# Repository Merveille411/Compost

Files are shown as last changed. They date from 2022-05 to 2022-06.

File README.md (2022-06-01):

# Compost Connecté

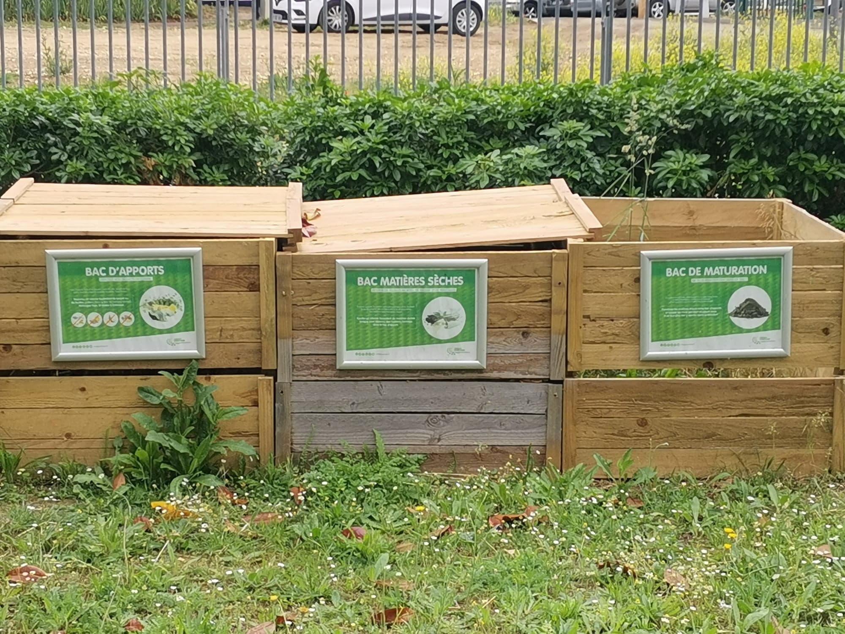
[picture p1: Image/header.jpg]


## Sommaire
- [Introduction](#introduction)
- [Résulat et problèmes rencontrés](#résulat-et-problèmes-rencontrés)
- [Conclusion](#conclusion)
- [À propos des dossiers](#à-propos-des-dossiers)

## Introduction

L’objectif de notre projet était de rendre le compost de l'ENSEA connecté et autonome, qu'il puisse envoyer un message d'alerte si les différents paramètre ne sont pas conforme.   
Nous arrivons donc au cahier des charges suivant :    
        
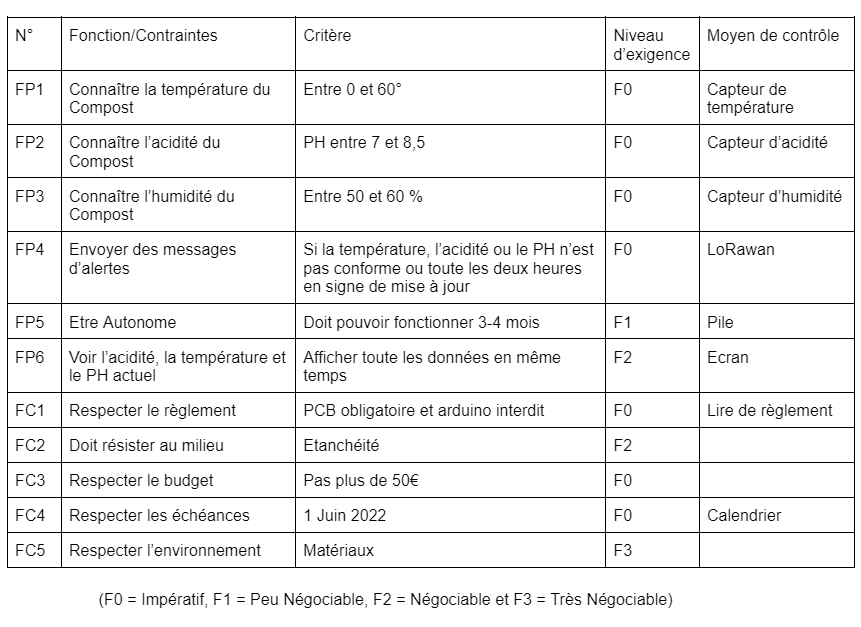
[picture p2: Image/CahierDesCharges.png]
     

FP1 : La référence du capteur de température est [SA56004AD](https://www.nxp.com/part/SA56004AD#/), il est à l’ENSEA. Il lui faut une tension entre 3,3 et 5 V et un courant de 100 microA. [Datasheet](https://www.nxp.com/docs/en/brochure/75015962.pdf)    
FP2 : La référence du capteur d’acidité est [32638](https://www.gotronic.fr/art-sonde-ph-interface-sen0161-21552.htm), il n’est pas à l’ENSEA, il coûte 32,30€. Il lui faut une tension de 5V. [Datasheet](https://wiki.dfrobot.com/PH_meter_SKU__SEN0161_)    
FP3 : La référence du capteur d’humidité est [893-7082](https://fr.rs-online.com/web/p/capteurs-de-temperature-et-d-humidite/8937082), il n’est pas à l’ENSEA, il coûte 11,26€. Il lui faut une tension de 5V et un courant de 1,5 mA. [Datasheet](https://www.te.com/commerce/DocumentDelivery/DDEController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)  
FP6 : La référence de l’écran est [4440](https://www.adafruit.com/product/4440), il est à l’ENSEA. Il lui faut une tension entre 3,3 et 5 V et un courant de 90 mA. [Datasheet](https://cdn-learn.adafruit.com/downloads/pdf/monochrome-oled-breakouts.pdf)   
    
Puisque nous avons deux capteurs et l'écran en connection I2C et le LoRa en connection UART, nous utiliserons un microprocesseur [STM32L412KBT6](https://www.digikey.fr/fr/products/detail/stmicroelectronics/STM32L412KBT6/9656219). Il est a l'ENSEA; [Datasheet](https://www.st.com/resource/en/datasheet/stm32l412kb.pdf)   
    
Le projet avancera d'après le planning prévisionnel suivant :
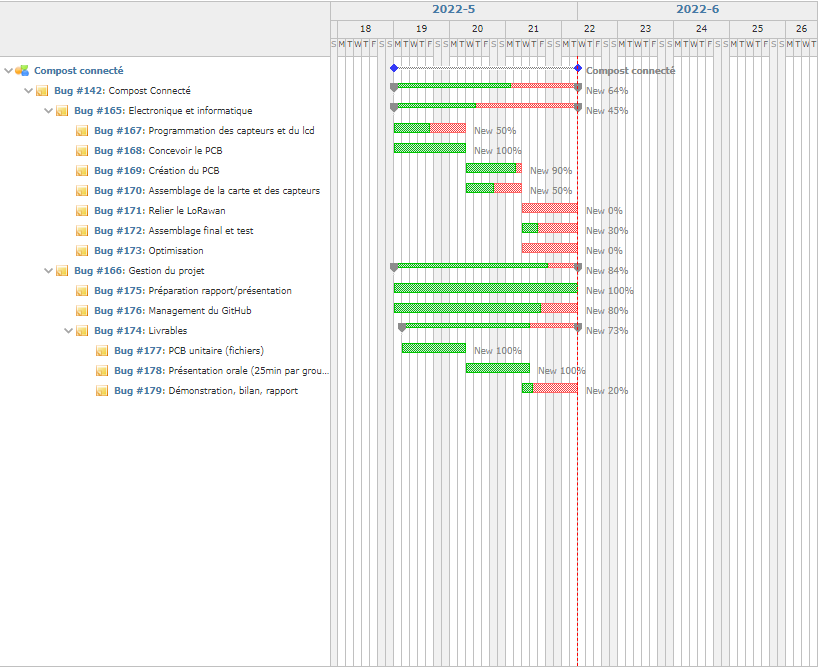
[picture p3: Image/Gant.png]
   

Les interactions entre les différents composants ainsi que la structure de base du projet est illustré de la manière suivante :
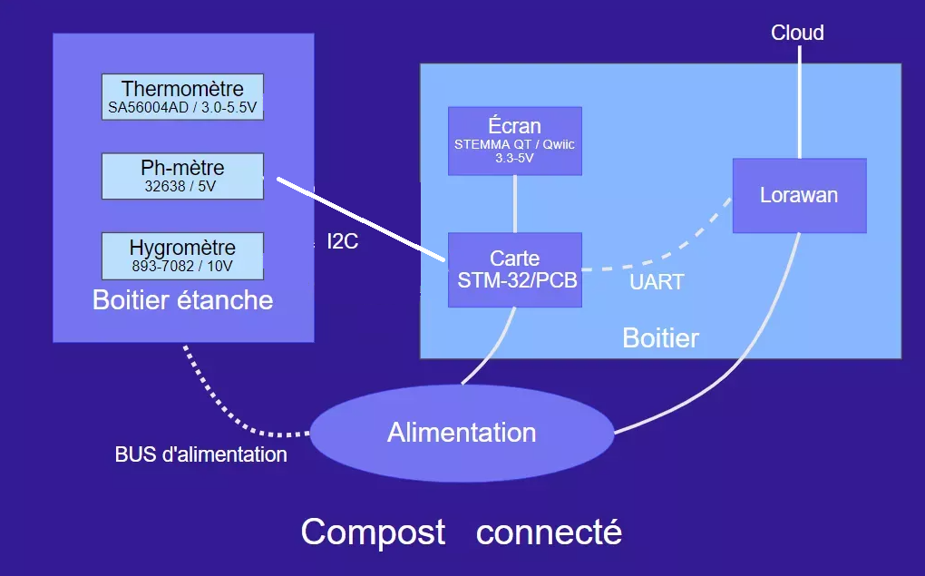
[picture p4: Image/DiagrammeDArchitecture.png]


## Résulat et problèmes rencontrés

Globalement, pour tout les PCB, le fichier contraintes a été respecté sauf pour celui du capteur de température. Donc notre PCB est inutilisable.               
Sur le PCB du compost, on a fait des erreurs sur les pin utilisés par le microprocesseur. Ducoup, on ne peut pas connecté le module LoRa et les capteur en I2C en même temps.
                
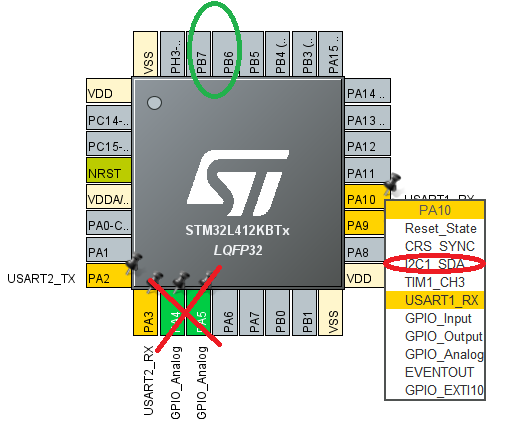
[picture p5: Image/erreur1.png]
   
                
Comme on peut le voir, le pA10 et pA9 permettent soit de faire la connection en UART ou en I2C tandis que pA4 et pA5 ne permet ne permet pas la connection en I2C comme prévu et il aurait fallu donc utilisé les pin pB6 et pB7.
                
Malgré ça, le PCB du compost et du capteur d'humidité ont leurs composants soudé parfaitement, sans erreur et les valeurs entre chaque point sont juste.               
                
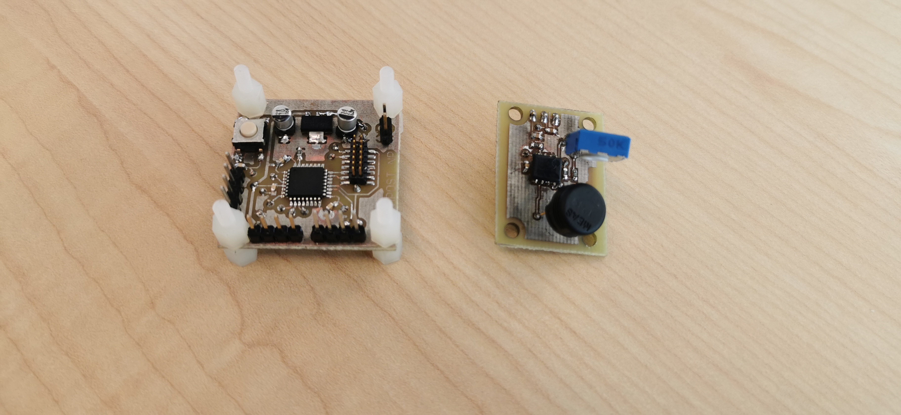
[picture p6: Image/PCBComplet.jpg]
   

De plus, le PCB du compost, qui contient le microprosseur a pu être flashé et donc il est prêt à être coder et à l'utilisation.         
        
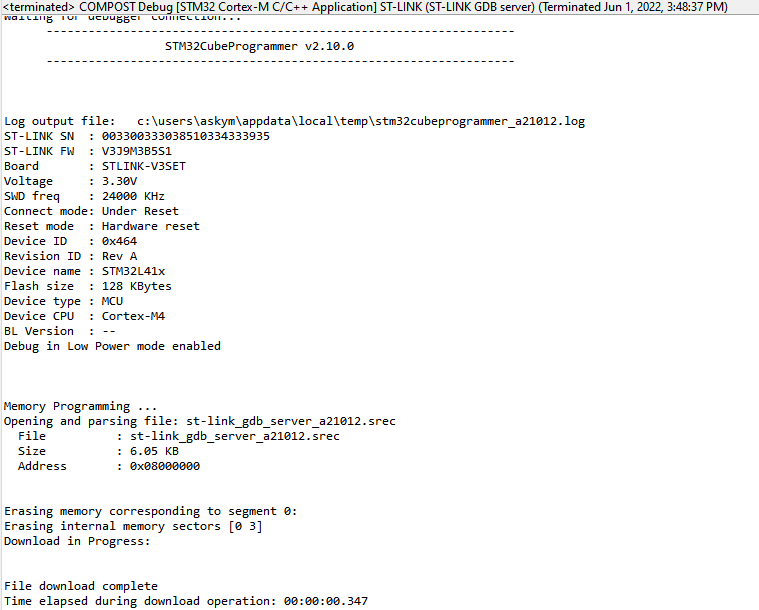
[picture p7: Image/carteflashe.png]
        
                
## Conclusion   
        
Pour conclure, il nous restez plus qu'à faire le code des différents composants et de réunir l’ensemble des parties pour faire un test global. Il faudrait aussi corriger les choix des pin sur le schéma du PCB du compost afin d'avoir la connection en I2C et UART. Ce projet nous a permis d'avoir une meilleur prise en main sur des logiciels du type EAGLE ou STM32CubeIDE. Nous avons également appris à s'attribuer des tâches de manière efficace, à communiquer et de se fixer des objectifs tout le long du projet.

## À propos des dossiers
**EAGLE/**    
                
  &emsp; &emsp;  **DRU/**    
  &emsp; &emsp;  Ce dossier contient le fichier contraintes utiliser pour les différents PCB du projet    
  &emsp; &emsp; `ENSEA_2022_04_08.dru`: Le fichier contrainte de l'ensea                
                
  &emsp; &emsp;  **Libraries/**    
  &emsp; &emsp;  Ce dossier contient tout les libraries des composants utiliser dans ce projet    
  &emsp; &emsp; `c1.lbr`: La librarie d'un condensateur de 470 uF utilisé dans le PCB de l'alimentation     
  &emsp; &emsp; `c2.lbr`: La librarie d'un condensateur de 100 uF utilisé dans le PCB de l'alimentation     
  &emsp; &emsp; `c3.lbr`: La librarie d'un condensateur de 470 pF utilisé dans le PCB de l'alimentation      
  &emsp; &emsp; `CapteurHumidite.lbr`: La librarie du capteur d'humidité     
  &emsp; &emsp; `CapteurTemperature.lbr`: La librarie du capteur de température     
  &emsp; &emsp; `cin.lbr`: La librarie d'un condensateur de 10 uF utilisé dans le PCB de l'alimentation ainsi que dans le PCB complet du compost      
  &emsp; &emsp; `cout.lbr`: La librarie d'un condensateur de 22 uF utilisé dans le PCB de l'alimentation ainsi que dans le PCB complet du compost      
  &emsp; &emsp; `l.lbr`: La librarie d'une bobine de 220 uH utilisé dans le PCB de l'alimentation     
  &emsp; &emsp; `MC34063A.lbr`: La librarie du régulateur à découpage utilisé dans le PCB de l'alimentation    
  &emsp; &emsp; `RegLineaire.lbr`: La librarie du régulateur linéaire utilisé dans le PCB de l'alimentation ainsi que dans le PCB complet du compost     
  &emsp; &emsp; `STM32_librairy.lbr`: La librarie du microproccesseur le PCB complet du compost          
                
  &emsp; &emsp;  **PCB/**   
  &emsp; &emsp;  Ce fichier contient tout les schémas et les boards des composants utiliser dans ce projet   
                
  &emsp; &emsp; `Alimentation.sch`: Le schéma du PCB de l'alimentation        
        
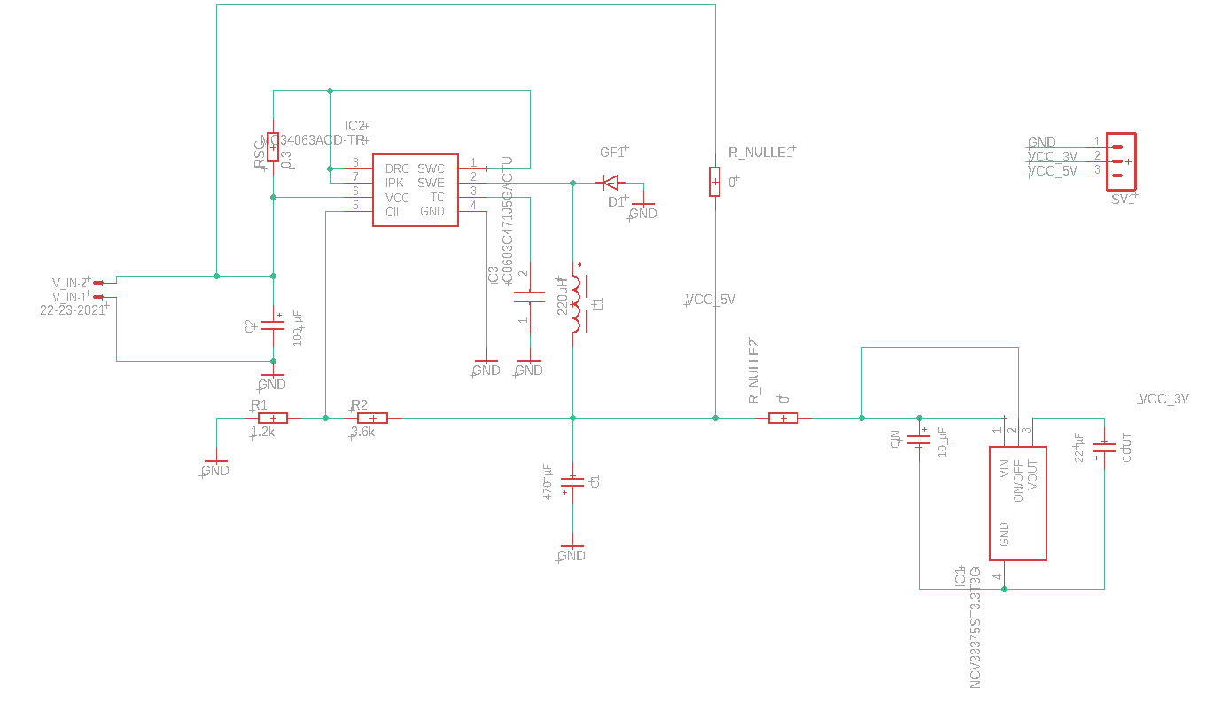
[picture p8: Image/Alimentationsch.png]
          
        
  &emsp; &emsp; `Alimentation.brd`: Le board du PCB de l'alimentation    
        
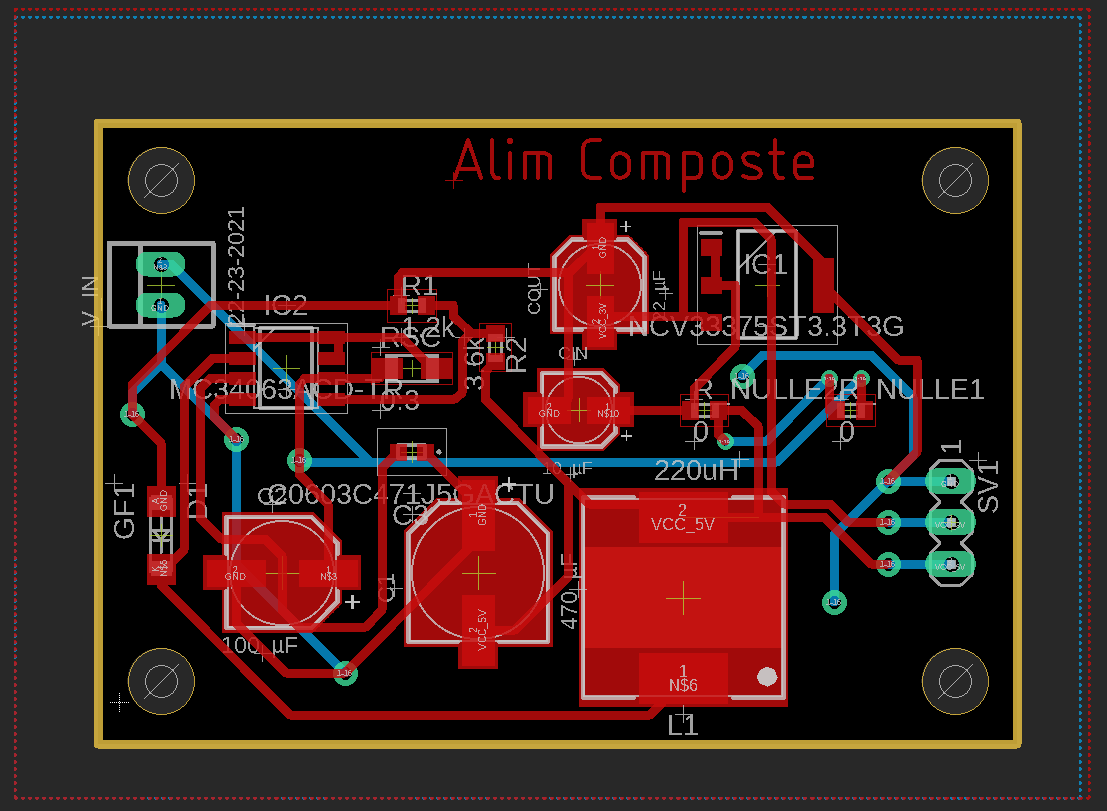
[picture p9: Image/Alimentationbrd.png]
      
        
  &emsp; &emsp; `CapteurHumidite.sch`: Le schéma du PCB du capteur d'humidité  
  
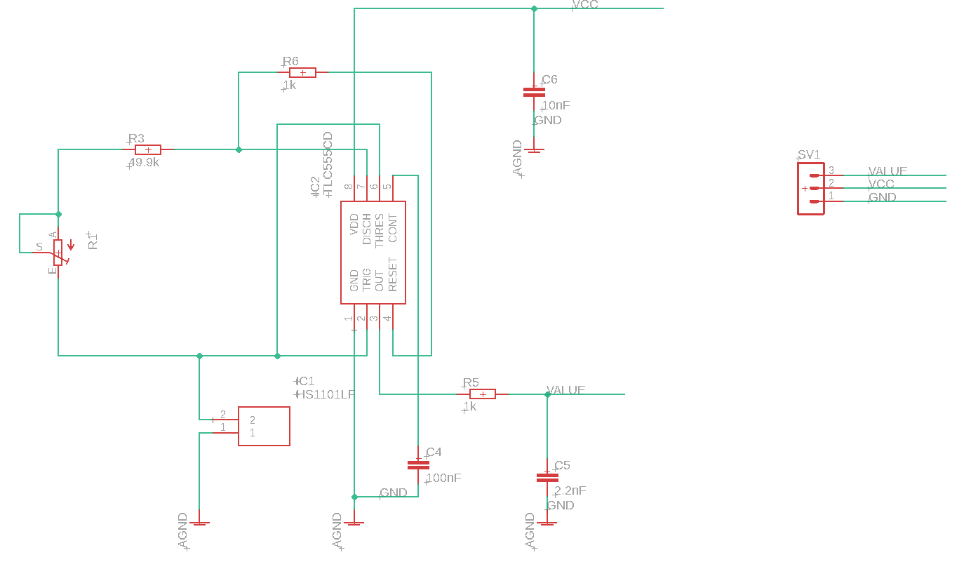
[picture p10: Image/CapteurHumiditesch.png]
       
            
  &emsp; &emsp; `CapteurHumidite.brd`: Le board du PCB du capteur d'humidité    
        
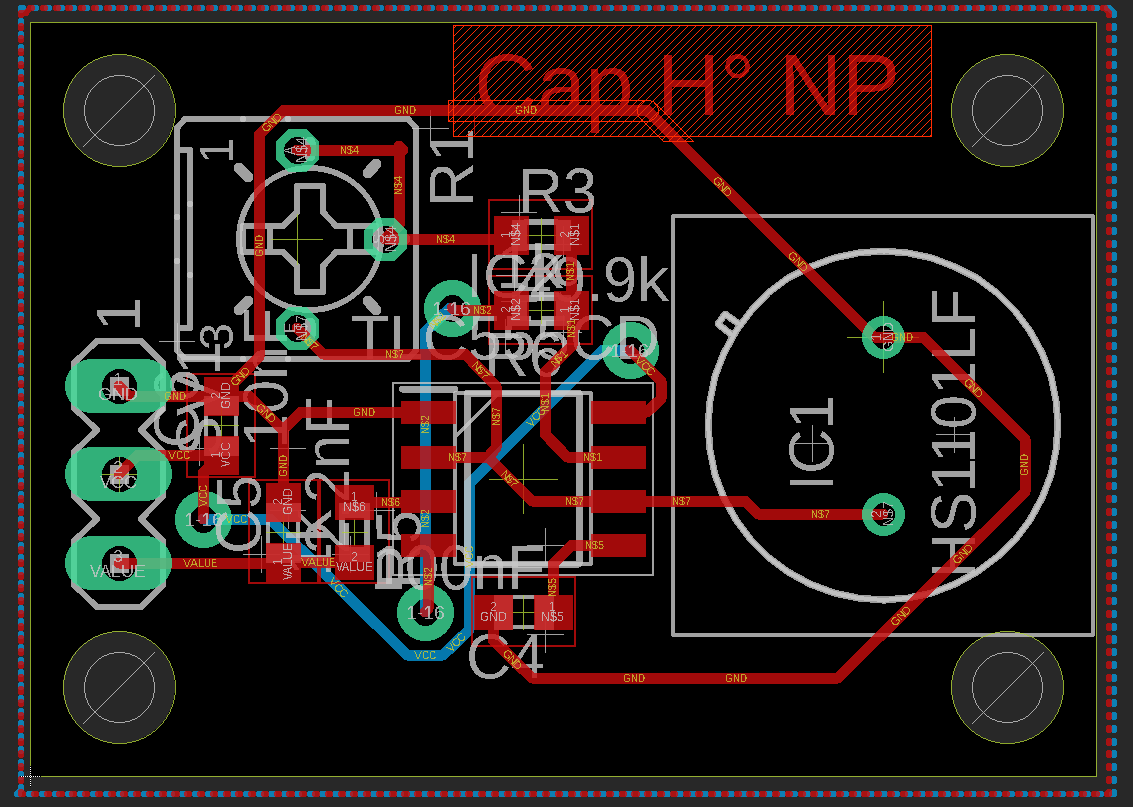
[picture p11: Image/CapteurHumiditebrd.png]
       
        
  &emsp; &emsp; `CapteurTemperature.sch`: Le schéma du PCB du capteur dde température  
        
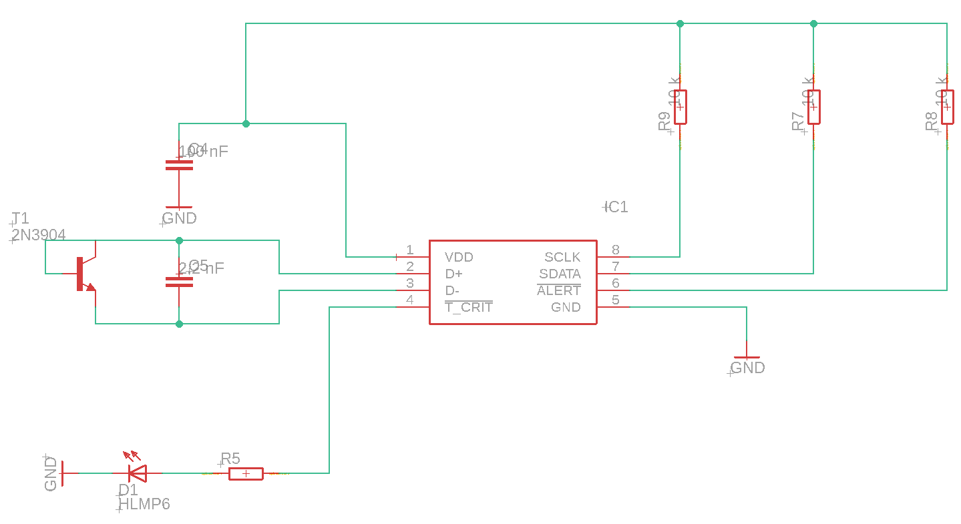
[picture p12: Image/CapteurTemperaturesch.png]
        
        
  &emsp; &emsp; `CapteurTemperature.brd`: Le board du PCB du capteur de température     
        
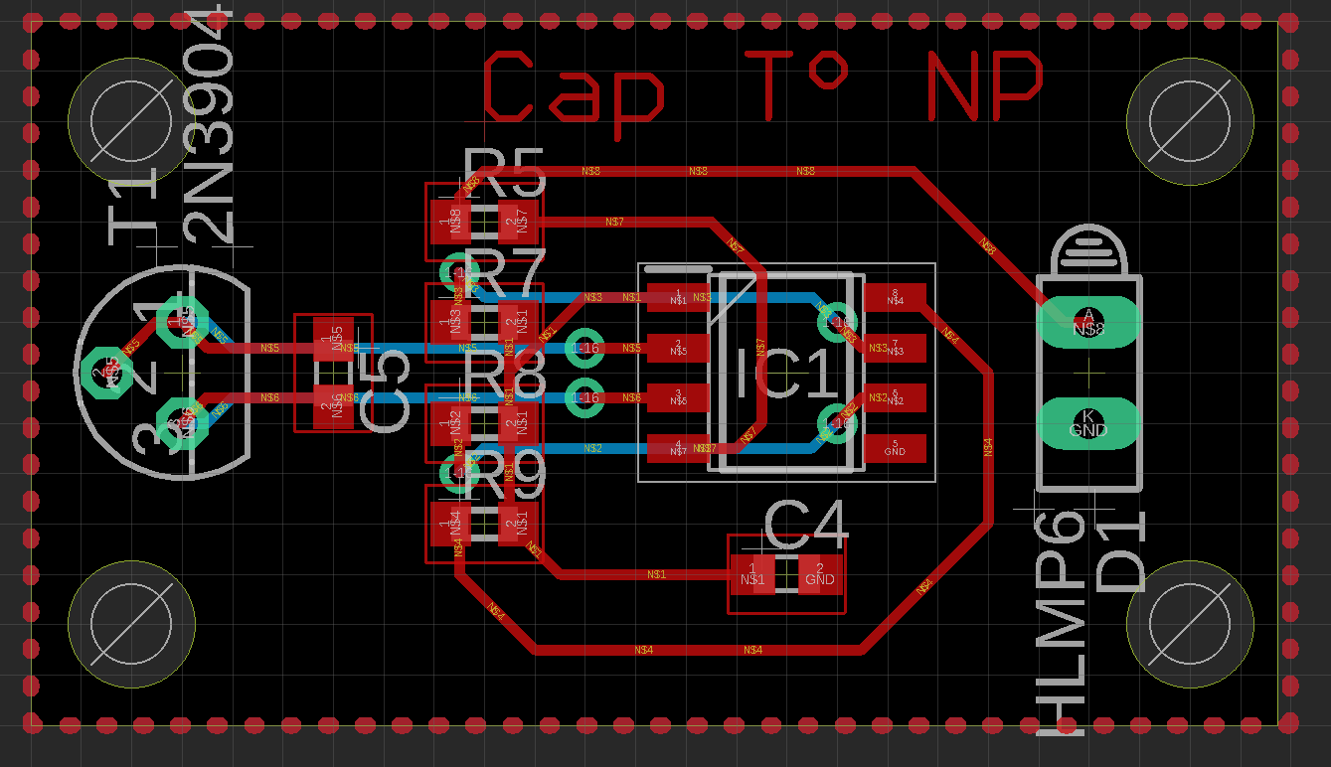
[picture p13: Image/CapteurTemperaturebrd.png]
        
        
  &emsp; &emsp; `PCBCompost.sch`:  Le schéma du PCB complet du compost  
        
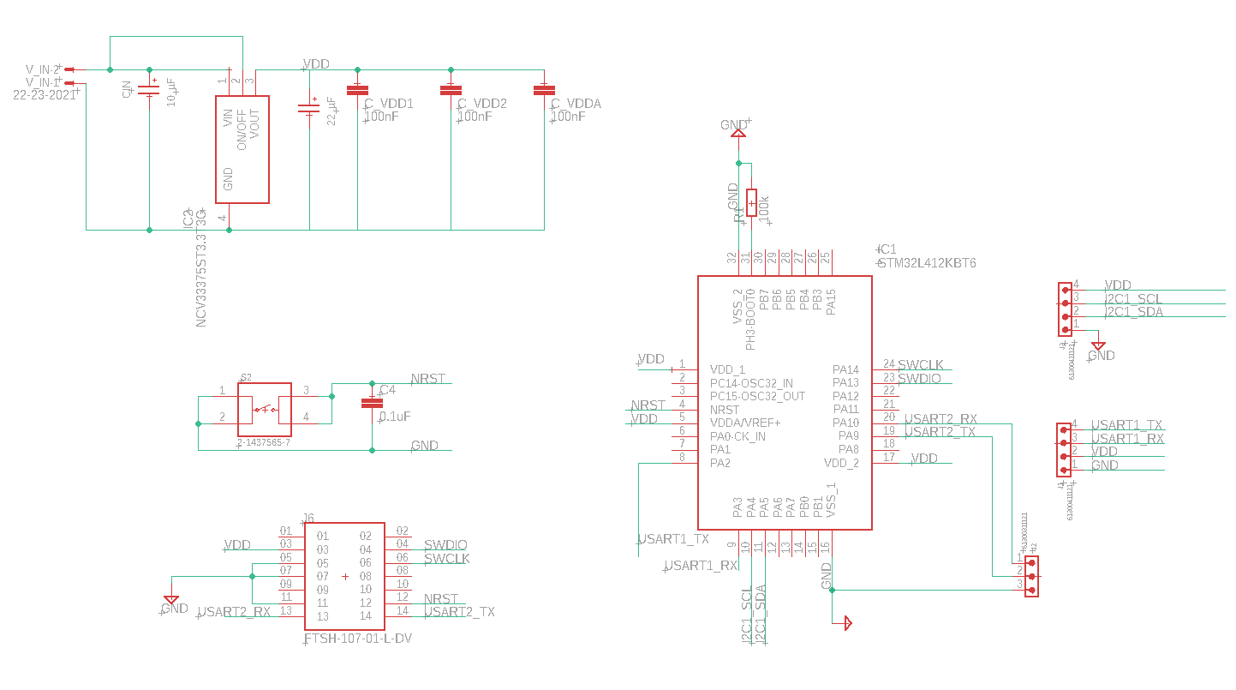
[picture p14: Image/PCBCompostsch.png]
        
        
  &emsp; &emsp; `PCBCompost.brd`:  Le board du PCB complet du compost  
        
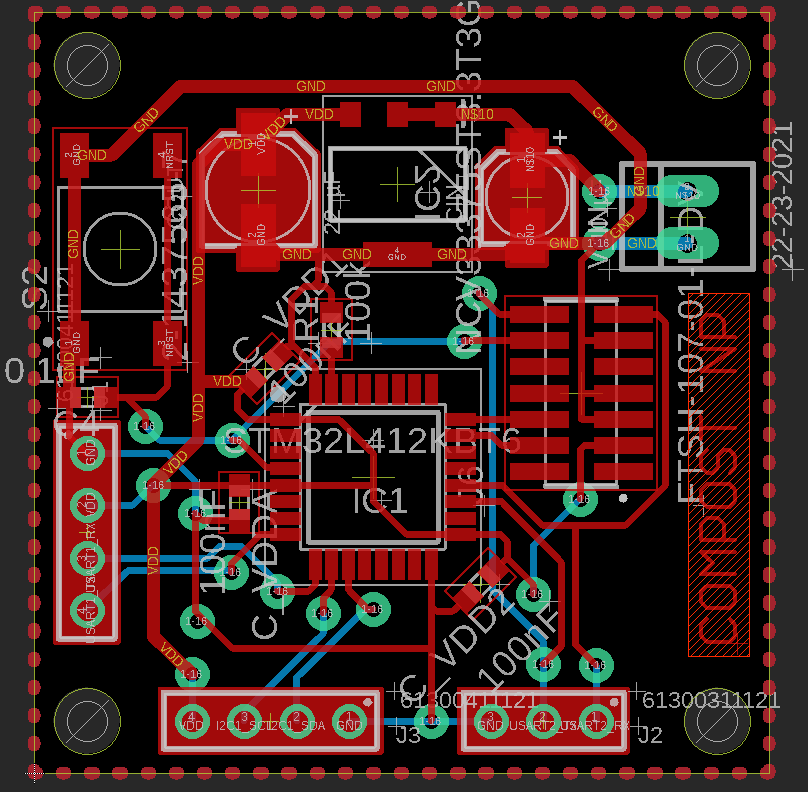
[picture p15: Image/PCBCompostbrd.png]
      
        
**Code/**               
                
&emsp; &emsp; Ce dossier contient le seul code qu'on a fait, il manque manque le code principal du micropocesseur, le code pHmètre, du campteur de température et d'humidité.           
&emsp; &emsp; `Screen.cpp`: Le code de l'écran en c++

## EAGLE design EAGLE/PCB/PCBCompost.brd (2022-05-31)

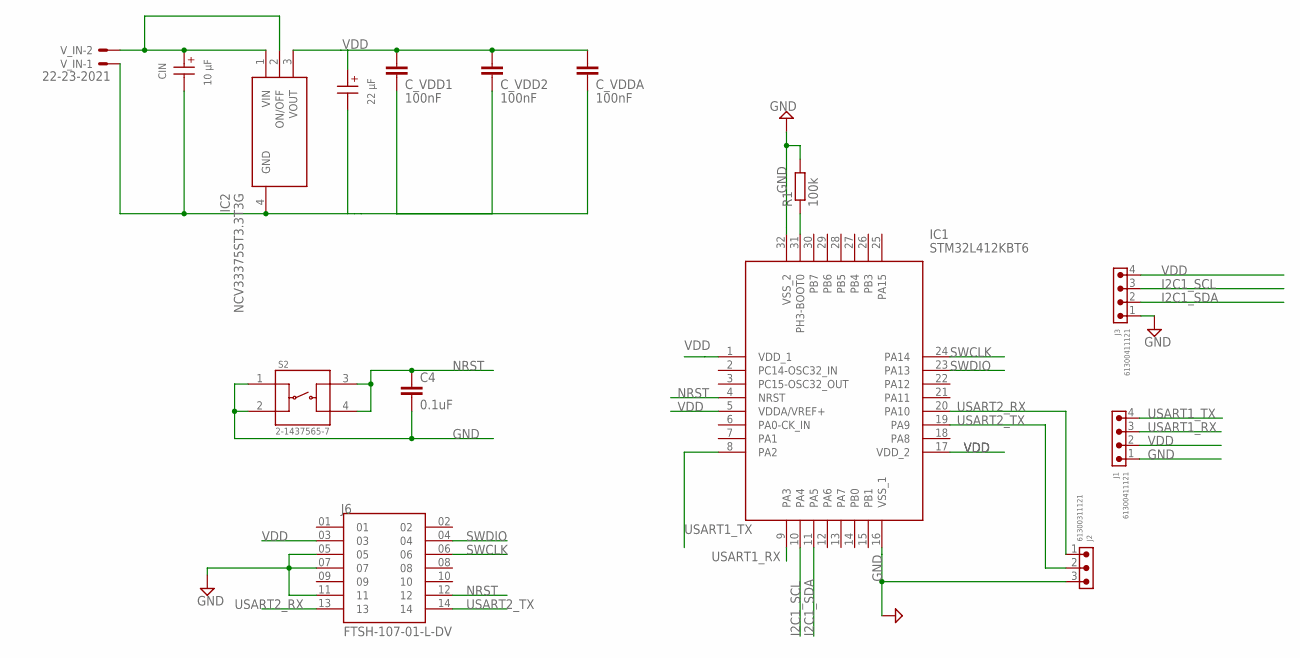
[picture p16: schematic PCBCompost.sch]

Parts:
C4: 0.1uF; C0603
CIN: 10 µF; WCAP-ASLL_4X5.5(DXL)
COUT: 22 µF; WCAP-ASLL_5X5.5(DXL)
C_VDD1, C_VDD2: 100nF; C0603
C_VDDA: 100nF; C0603
IC1: STM32L412KBT6; QFP80P900X900X160-32N
IC2: NCV33375ST3.3T3G; SOT230P700X175-4N
J1, J3: 61300411121
J2: 61300311121
J6: FTSH-107-01-L-DV; SAMTEC_FTSH-107-01-L-DV
R1: 100k; R0603
S2: 2-1437565-7; SW_2-1437565-7
V_IN: 22-23-2021

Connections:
GND: C4.2, CIN.2 (-), COUT.2 (-), C_VDD1.2, C_VDD2.2, C_VDDA.2, IC1.16 (VSS_1), IC1.32 (VSS_2), IC2.4 (GND), J1.1, J2.3, J3.1, J6.05, J6.07, J6.11, R1.2, S2.1, S2.2, V_IN.1
I2C1_SCL: IC1.10 (PA4), J3.3
I2C1_SDA: IC1.11 (PA5), J3.2
unnamed: IC1.31 (PH3-BOOT0), R1.1
unnamed: CIN.1 (+), IC2.1 (VIN), IC2.2 (ON/OFF), V_IN.2
NRST: C4.1, IC1.4 (NRST), J6.12, S2.3, S2.4
SWCLK: IC1.24 (PA14), J6.06
SWDIO: IC1.23 (PA13), J6.04
USART1_RX: IC1.9 (PA3), J1.3
USART1_TX: IC1.8 (PA2), J1.4
USART2_RX: IC1.20 (PA10), J2.1, J6.13
USART2_TX: IC1.19 (PA9), J2.2, J6.14
VDD: COUT.1 (+), C_VDD1.1, C_VDD2.1, C_VDDA.1, IC1.1 (VDD_1), IC1.5 (VDDA/VREF+), IC1.17 (VDD_2), IC2.3 (VOUT), J1.2, J3.4, J6.03

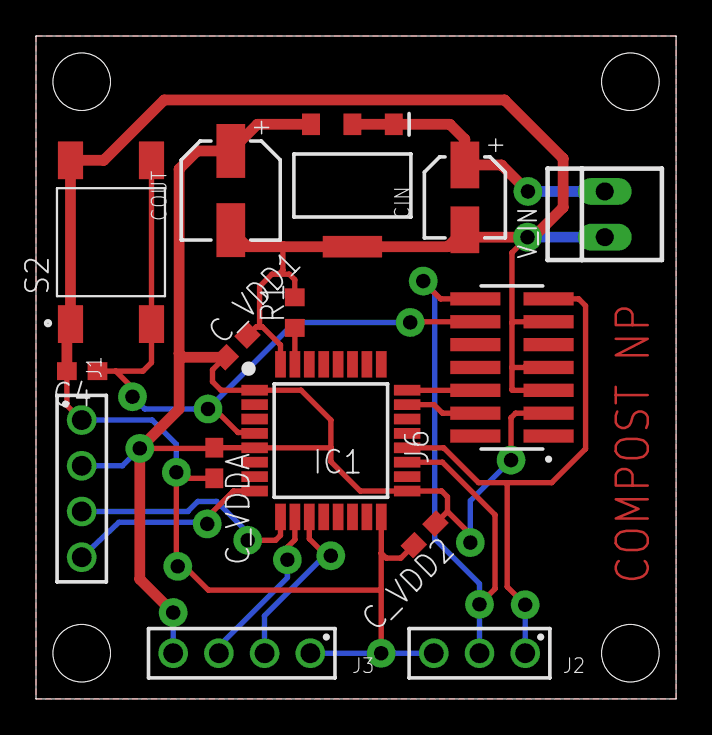
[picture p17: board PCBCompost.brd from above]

Board: 2 copper layers, 35.6 x 36.8 mm, 15 parts (0 on the bottom side), 13 nets.

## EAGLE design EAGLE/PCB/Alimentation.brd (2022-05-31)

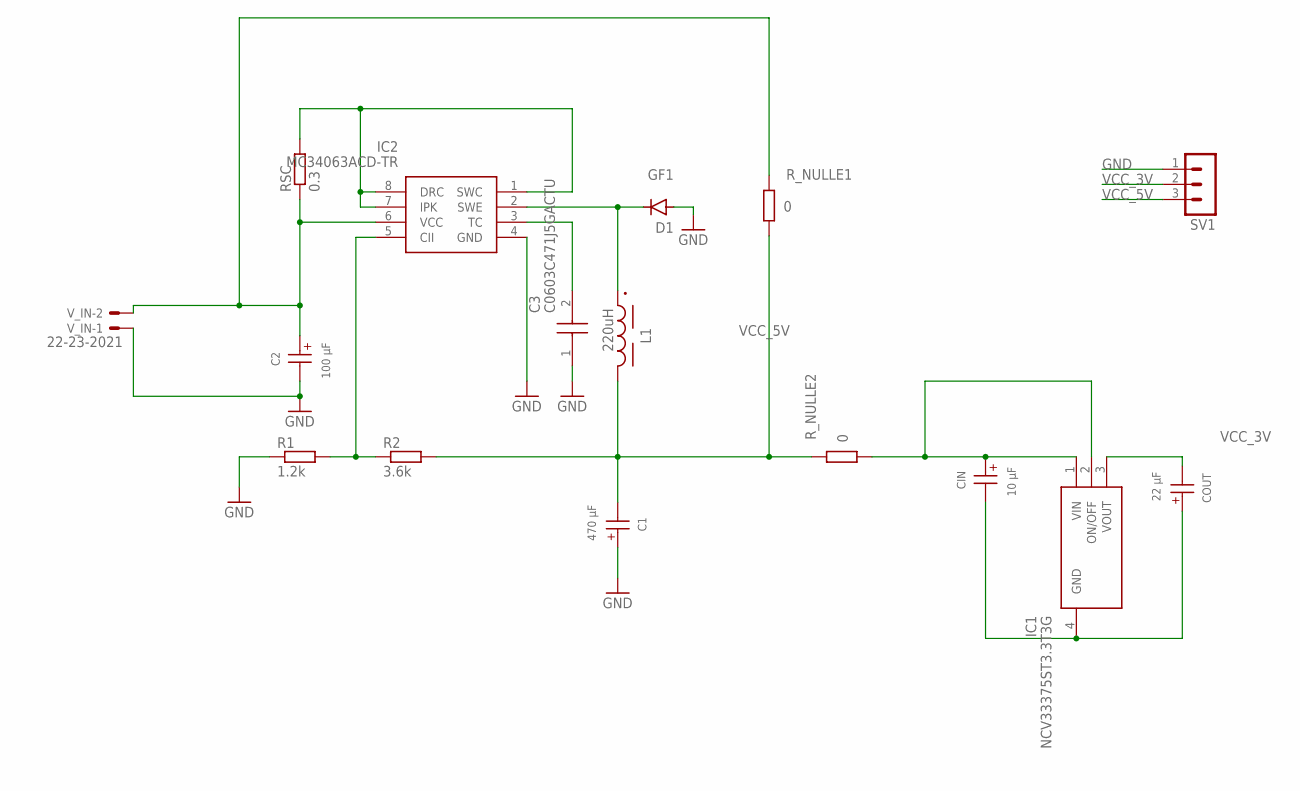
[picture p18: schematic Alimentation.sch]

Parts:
C1: 470 µF; WCAP-ASLL_8X10.5(DXL)
C2: 100 µF; WCAP-ASLL_6.3X7.7(DXL)
C3: C0603C471J5GACTU; C0603
CIN: 10 µF; WCAP-ASLL_4X5.5(DXL)
COUT: 22 µF; WCAP-ASLL_5X5.5(DXL)
D1: GF1; SMA-DO214AC
IC1: NCV33375ST3.3T3G; SOT230P700X175-4N
IC2: MC34063ACD-TR; SOIC127P600X175-8N
L1: 220uH; WE-PDA_1260
R1: 1.2k; R0603
R2: 3.6k; R0603
RSC: 0.3; R1206W
R_NULLE1, R_NULLE2: 0; R0603
SV1: MA03-1
V_IN: 22-23-2021

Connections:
GND: C1.1 (+), C2.2 (-), C3.1, CIN.2 (-), COUT.1 (+), D1.A, IC1.4 (GND), IC2.4 (GND), R1.1, SV1.1, V_IN.1
unnamed: IC2.5 (CII), R1.2, R2.1
unnamed: IC2.1 (SWC), IC2.7 (IPK), IC2.8 (DRC), RSC.2
unnamed: C2.1 (+), IC2.6 (VCC), RSC.1, R_NULLE1.2, V_IN.2
unnamed: D1.K (C), IC2.2 (SWE), L1.1
unnamed: C3.2, IC2.3 (TC)
unnamed: CIN.1 (+), IC1.1 (VIN), IC1.2 (ON/OFF), R_NULLE2.1
VCC_3V: COUT.2 (-), IC1.3 (VOUT), SV1.2
VCC_5V: C1.2 (-), L1.2, R2.2, R_NULLE1.1, R_NULLE2.2, SV1.3

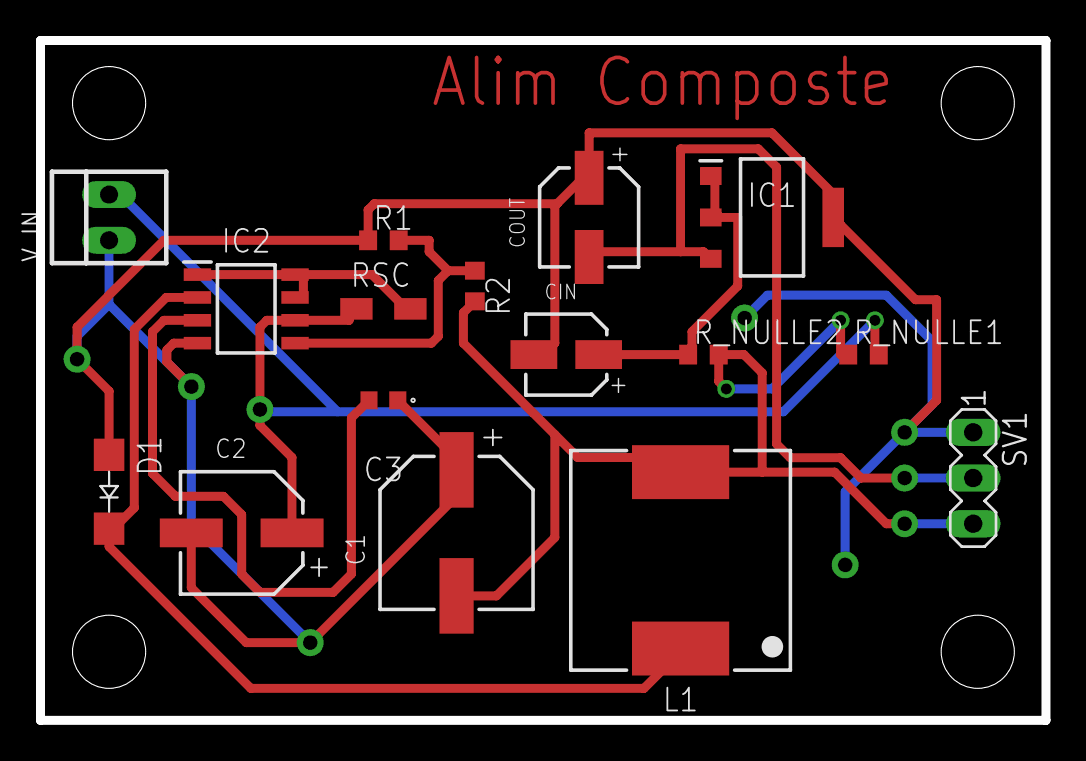
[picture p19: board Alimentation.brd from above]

Board: 2 copper layers, 55.9 x 37.8 mm, 16 parts (0 on the bottom side), 9 nets.

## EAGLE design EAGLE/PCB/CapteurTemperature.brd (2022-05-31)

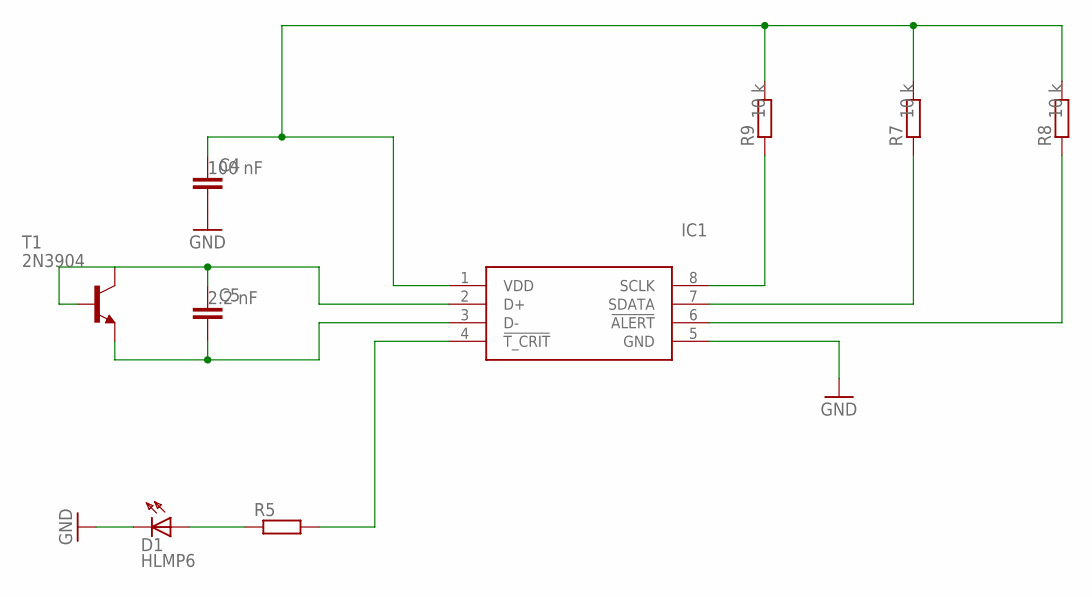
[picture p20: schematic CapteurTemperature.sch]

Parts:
C4, C5: C-EUC0603; C0603
D1: HLMP6
IC1: SA56004AD,118; SOIC127P600X175-8N
R5, R7, R8, R9: RR0603; R0603
T1: 2N3904; TO92

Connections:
GND: C4.2, D1.K, IC1.5 (GND)
unnamed: C4.1, IC1.1 (VDD), R7.2, R8.2, R9.2
unnamed: IC1.6 (!ALERT), R8.1
unnamed: IC1.7 (SDATA), R7.1
unnamed: IC1.8 (SCLK), R9.1
unnamed: C5.1, IC1.2 (D+), T1.1 (C), T1.2 (B)
unnamed: C5.2, IC1.3 (D-), T1.3 (E)
unnamed: IC1.4 (!T_CRIT), R5.2
unnamed: D1.A, R5.1

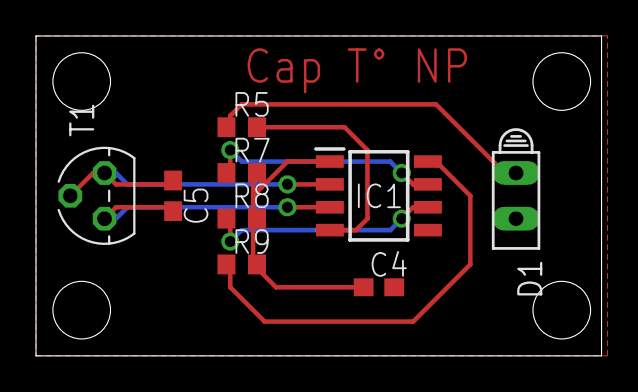
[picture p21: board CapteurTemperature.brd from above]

Board: 2 copper layers, 31.4 x 17.8 mm, 9 parts (0 on the bottom side), 9 nets.

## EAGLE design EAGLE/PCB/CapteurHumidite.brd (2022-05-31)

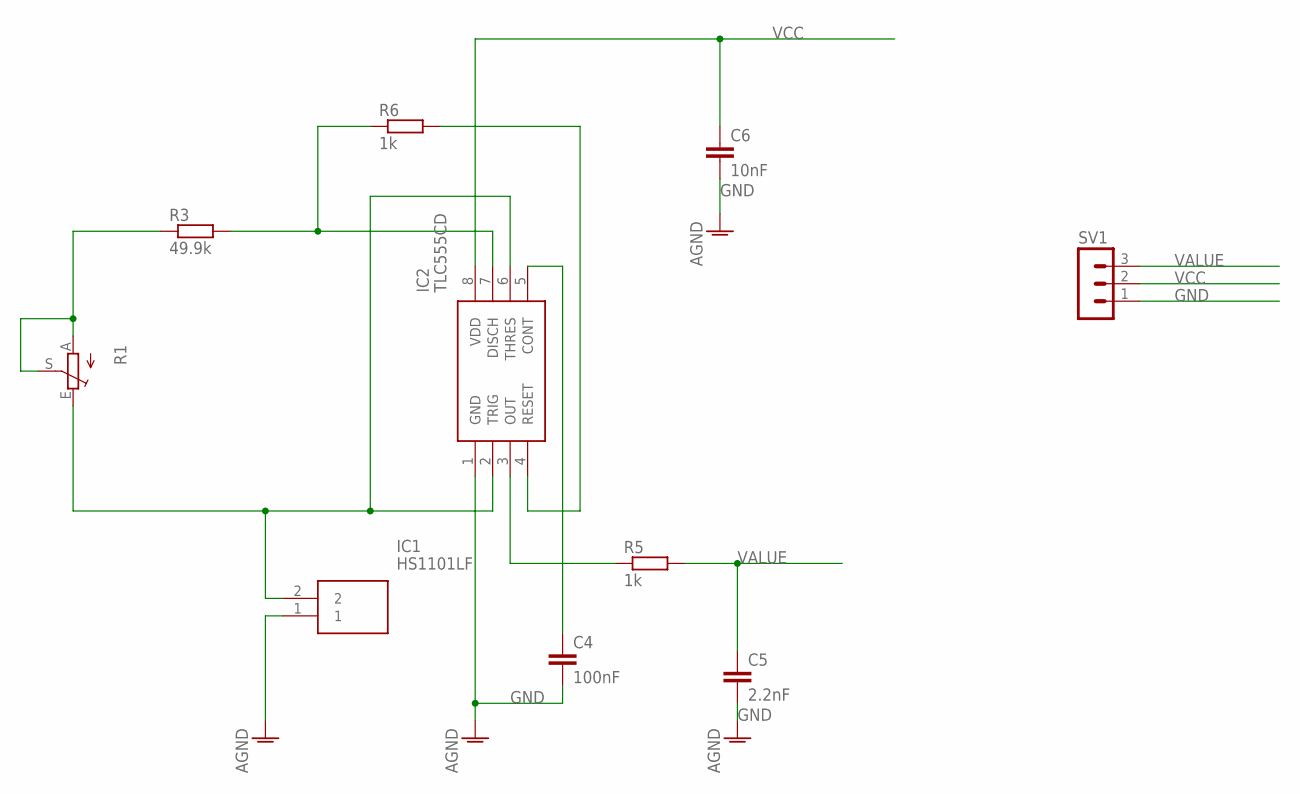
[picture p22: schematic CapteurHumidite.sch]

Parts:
C4: 100nF; C0603
C5: 2.2nF; C0603
C6: 10nF; C0603
IC1: HS1101LF
IC2: TLC555CD; SOIC127P600X175-8N
R1: TRIM_EU-B25P; B25P
R3: 49.9k; R0603
R5, R6: 1k; R0603
SV1: MA03-1

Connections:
GND: C4.2, C5.2, C6.2, IC1.1, IC2.1 (GND), SV1.1
unnamed: IC2.7 (DISCH), R3.2, R6.1
unnamed: IC2.4 (RESET), R6.2
unnamed: R1.A, R1.S, R3.1
unnamed: C4.1, IC2.5 (CONT)
unnamed: IC2.3 (OUT), R5.1
unnamed: IC1.2, IC2.2 (TRIG), IC2.6 (THRES), R1.E
VALUE: C5.1, R5.2, SV1.3
VCC: C6.1, IC2.8 (VDD), SV1.2

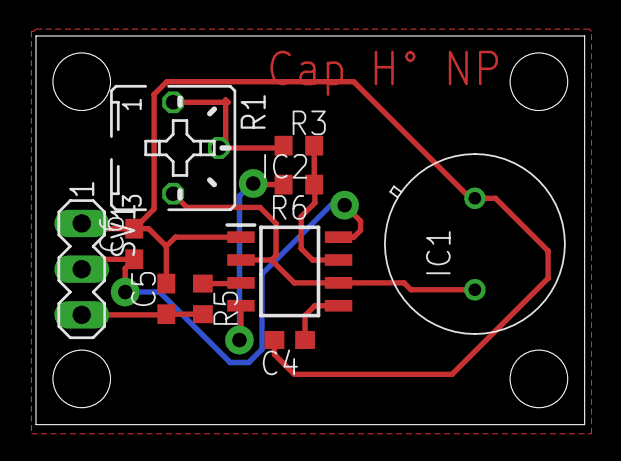
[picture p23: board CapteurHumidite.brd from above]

Board: 2 copper layers, 30.5 x 21.6 mm, 10 parts (0 on the bottom side), 9 nets.

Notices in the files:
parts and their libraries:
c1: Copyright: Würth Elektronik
